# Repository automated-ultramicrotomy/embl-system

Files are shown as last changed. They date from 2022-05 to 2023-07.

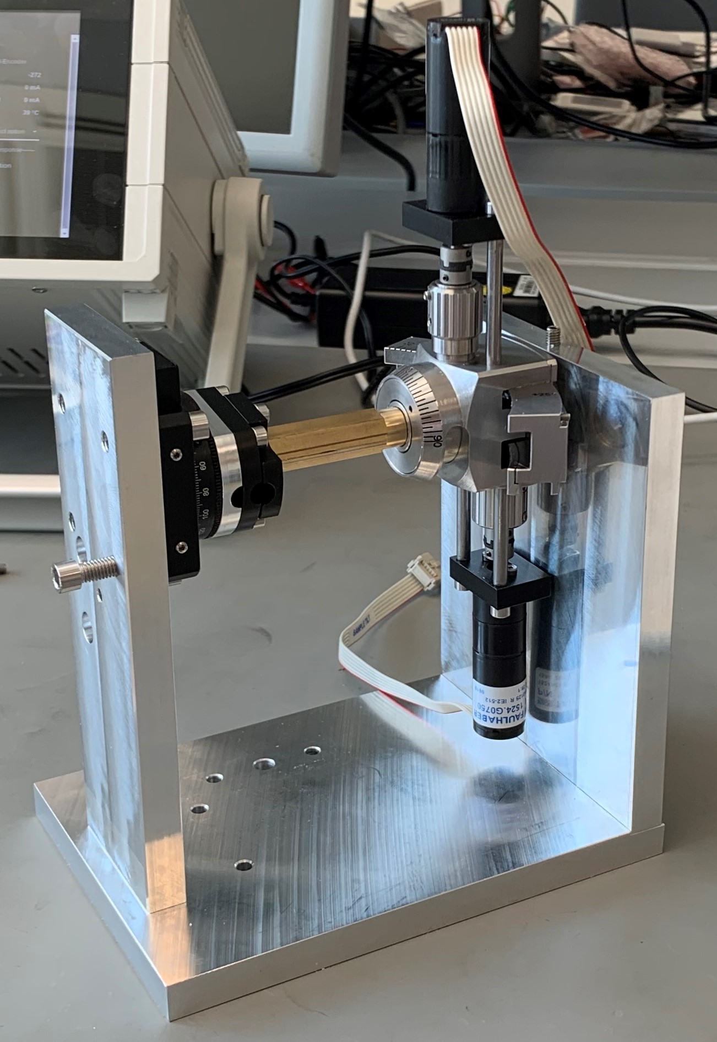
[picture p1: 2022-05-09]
Images/calibration/sample-rotation-images/sample-rotation-4.jpg

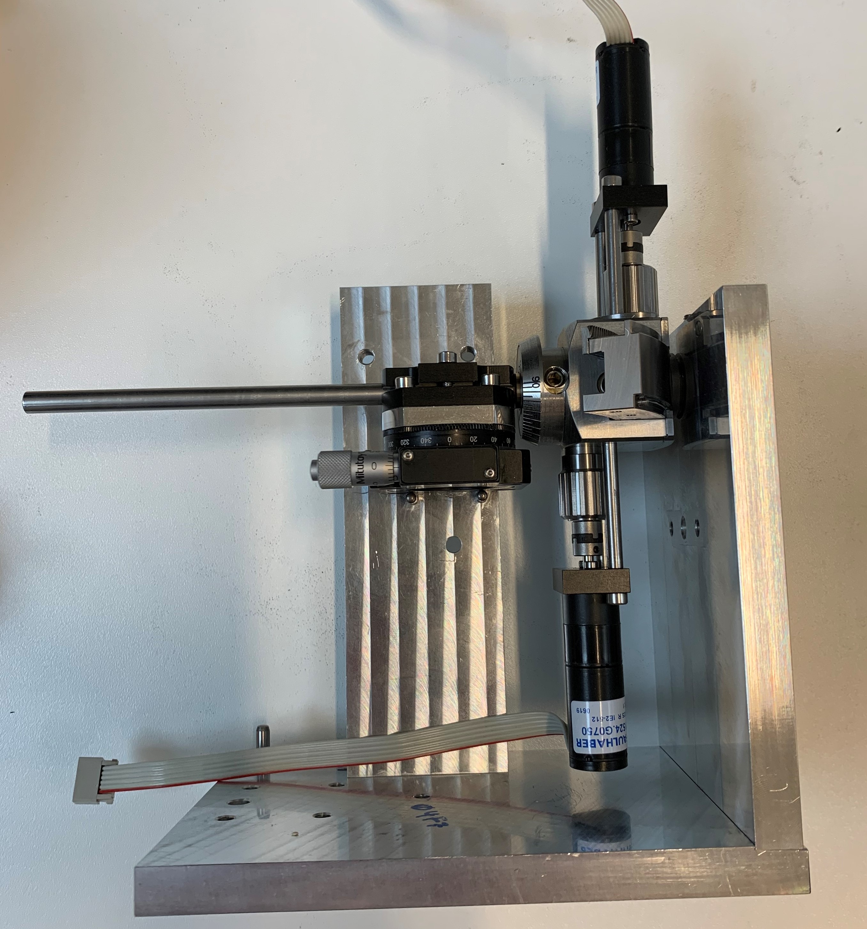
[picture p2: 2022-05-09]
Images/calibration/sample-tilt-images/sample-tilt-3.jpg

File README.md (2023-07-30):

# embl-system

Files for the motorised system from EMBL, built on a Leica UC7 ultramicrotome.

- **CAD Parts** - CAD models of the main parts
- **Code** - node-red flow for user interface
- **Images**  - diagrams / images of the system and subsystems
- **parts_list.pdf** - list of the main parts for the motorised system

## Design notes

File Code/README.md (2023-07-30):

# node-red

Files for the user-interface / electronics of the motorised system.

**node-red-flow.json** gives the entire 'flow' json for the user interface. Once Node-RED (https://nodered.org/) is installed,
the flow can be loaded by selecting `import` from the menu, and providing this `.json` file. 

This also requires the following nodes to be installed: 
  * node-red-dashboard (https://flows.nodered.org/node/node-red-dashboard), 
  * node-red-node-serialport (https://flows.nodered.org/node/node-red-node-serialport)

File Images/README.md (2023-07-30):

# System Images

Images/diagrams of different system components

- **box-images** - images of the interface box
- **calibration** - diagrams / images of the calibration setup
- **knife-tilt** - diagrams / images of the knife + motor
- **sample-tilt-rotation**  - diagrams / images of the arc + motors
- **user-interface** - screenshot images of the node-red flows for the user interface

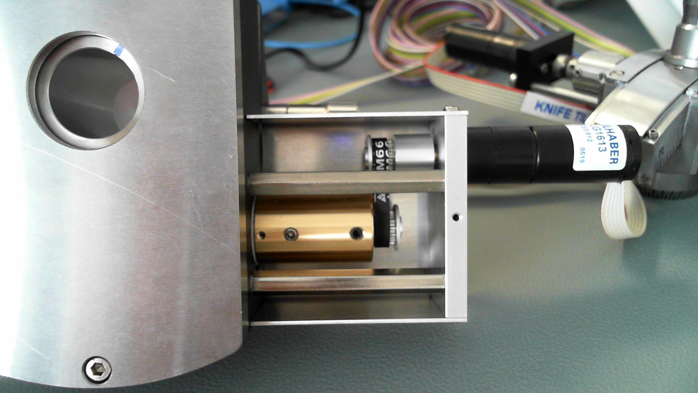
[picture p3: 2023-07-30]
Images/knife-tilt/knife_underside_3.jpg

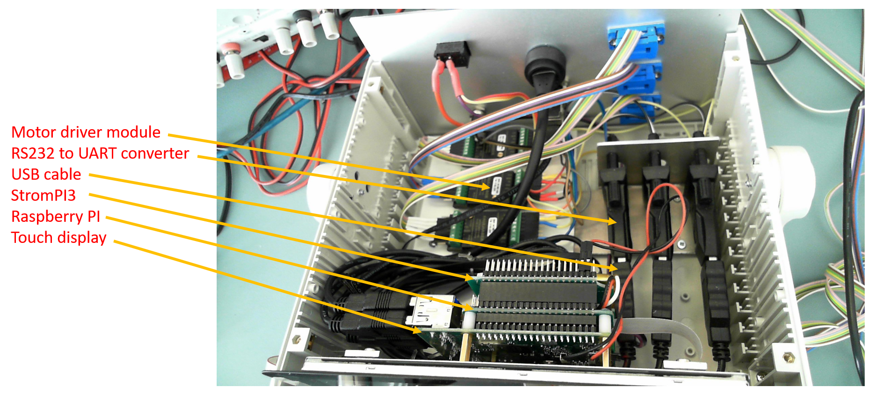
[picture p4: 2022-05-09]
Images/box-images/inside-the-box-with-labels.png

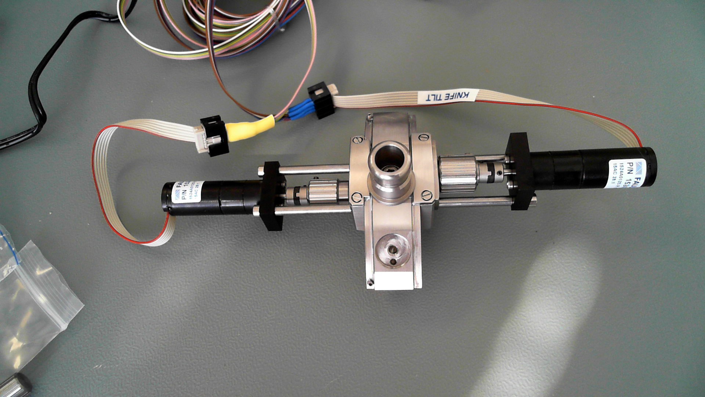
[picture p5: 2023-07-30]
Images/sample-tilt-rotation/arc_back_1.jpg

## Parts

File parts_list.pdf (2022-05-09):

Units | Item | Manufacturer | Reference
1 | Case Bopla UM 52011 L 224x198,9x72,4 | Distrelec | 150-43-162
1 | Netzgerät getaktet, 60W, 12Vdc / 5A (jack 2.1x5x5x11mm) | RS | 175-3285
2 | Motor Combi 1524A012S R IE2-512 15AC28:1 | FAULHABER | 1524.G0750
1 | Motor Combi 1524B012S R IE2-512 15AC52:1 | FAULHABER | 1524.G1613
3 | Controller MCDC3002 S RS | FAULHABER | 650,001,488
1 | Strom Pi 3 | Reichelt | RASP STROM PI 3
1 | Battery Raspberry Pi | Reichelt | RPI STROMPI AKKU
1 | Raspberry Pi 7" Touchscreen Display | Reichelt | RASPBERRY PI 7TD
1 | Raspberry Pi 3 B | Reichelt | Raspberry Pi 3 B
3 | USB 2.0 Kabel, A Stecker auf A Buchse, 30 cm | Reichelt | AK 669-0,3
3 | Delock USB2.0 auf Seriell Adapter RS232 | Reichelt | DELOCK 61460
1 | Panels | BetaLayout
4 | Synchronscheiben (rotaciones) | Misumi | HTPA15S2M040-K-P3
2 | Super Torque S2M 4mm x 66mm (belts) | Misumi | 40S2M66
2 | Flex joint | Misumi | MCO8-3-3
1 | USB connector panel | Digi-Key | APC1748-ND
1 | Ethernet connector panel | Digi-Key | EHRJ45P6S-ND
1 | TC-R13-66A-02 switch 250V/6A | Conrad El. | 1587515 - 62
1 | CONN PWR JACK 2X5.5MM | Digi-Key | CP-065A-ND
3 | WR-DSUB Female IDC Connector | Würth | 618 009 227 221
3 | WR-DSUB Male IDC Connector | Würth | 618 009 221 823
3 | WR-DSUB Plastic Hood, 9 pins | Würth | 618 009 253 22

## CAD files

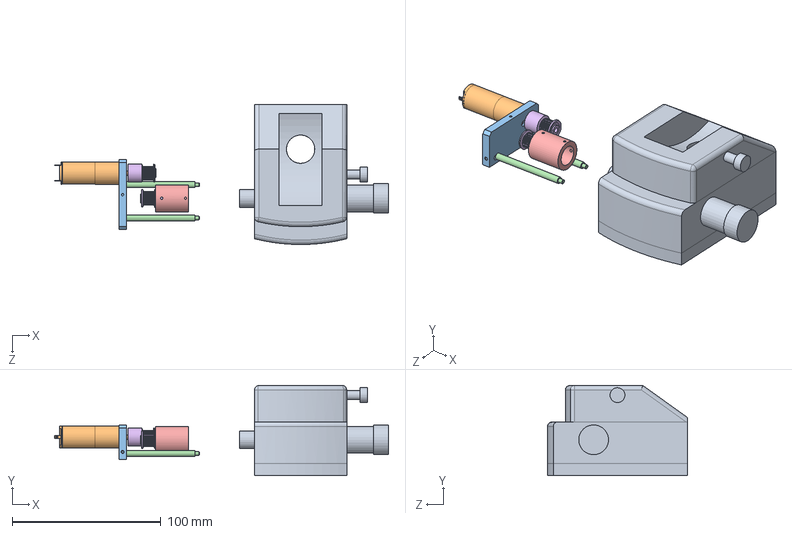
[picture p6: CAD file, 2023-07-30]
CAD Parts/Solidworks 2022 Models/knife-tilt/BG-YS-Messturm-01.SLDASM
224.2 x 60.5 x 94.0 mm
Messturm
1524T_SR
50-AL-0002-00
50-AL-0005-00 x 2
50-AL-0004-00
_HTPA15S2M060-K-H3_a.stp x 2

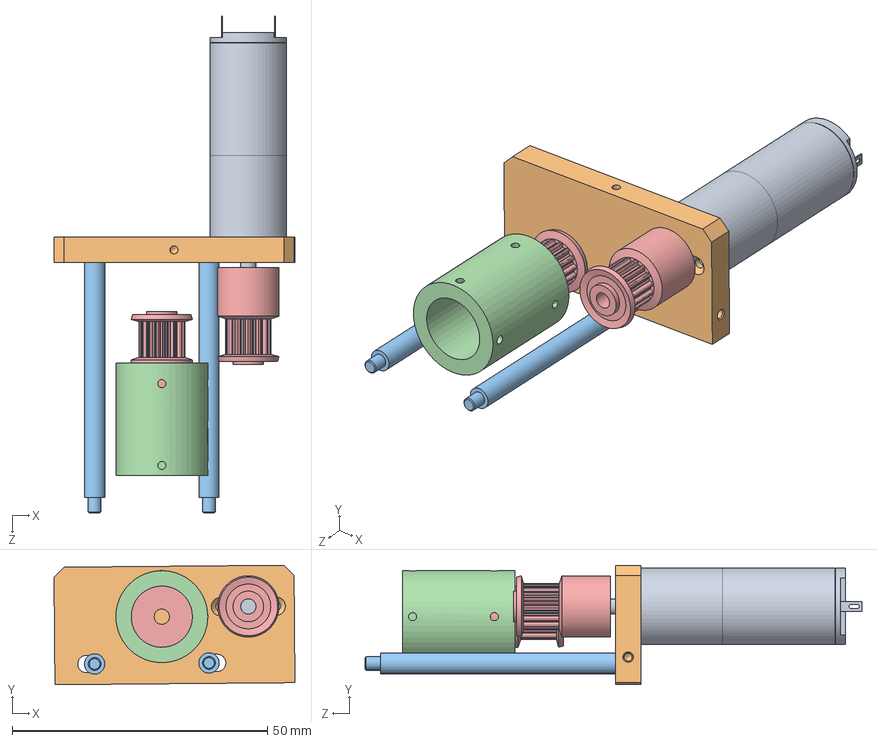
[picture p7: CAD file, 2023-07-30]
CAD Parts/Solidworks 2022 Models/knife-tilt/motor-mount/BG-Alfons-0000-00.SLDASM
47.2 x 23.4 x 97.2 mm
1524T_SR
50-AL-0002-00
50-AL-0005-00 x 2
50-AL-0004-00
_HTPA15S2M060-K-H3_a.stp x 2

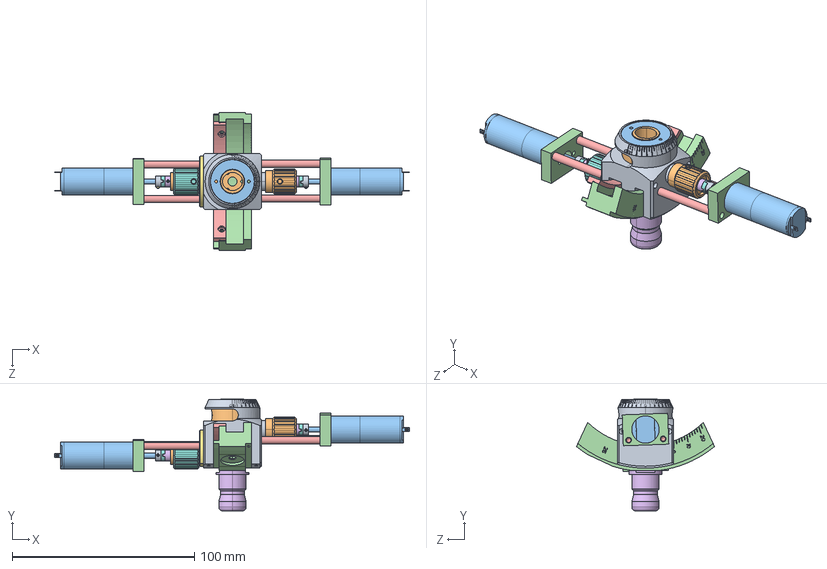
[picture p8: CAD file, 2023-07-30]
CAD Parts/Solidworks 2022 Models/sample-tilt-rotation/BG-YS-Segmentbogen-01.SLDASM
195.0 x 61.4 x 75.9 mm
16-708-031-109-Z-0000.stp
701731745.stp
16-705-831-540-Z-0000.stp
702531341.stp
702531342.stp
705831360.stp
702531344.stp
705831361.stp
700331086.stp
705831362.stp
1524T_SR x 2
50-AL-0001-00 x 2
50-AL-0005-00 x 4
_MCO6-1.5-1.5_co.stp x 2
_SET-SCREW1.6-3.stp x 4
_MCO_spacer6_s.stp x 2
_MCO6-1.5-1.5_co_r.stp x 2
50-AL-0006-00 x 2

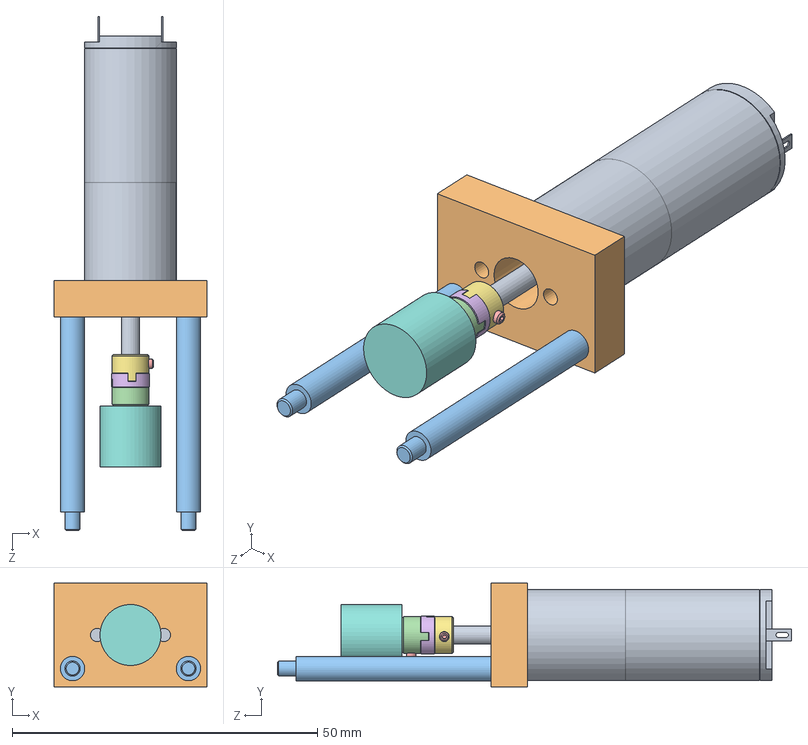
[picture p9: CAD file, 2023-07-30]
CAD Parts/Solidworks 2022 Models/sample-tilt-rotation/motor-mount/BG-Alfons-0001-00.SLDASM
25.0 x 17.0 x 84.2 mm
1524T_SR
50-AL-0001-00
50-AL-0005-00 x 2
_MCO6-1.5-1.5_co.stp
_SET-SCREW1.6-3.stp x 2
_MCO_spacer6_s.stp
_MCO6-1.5-1.5_co_r.stp
50-AL-0006-00

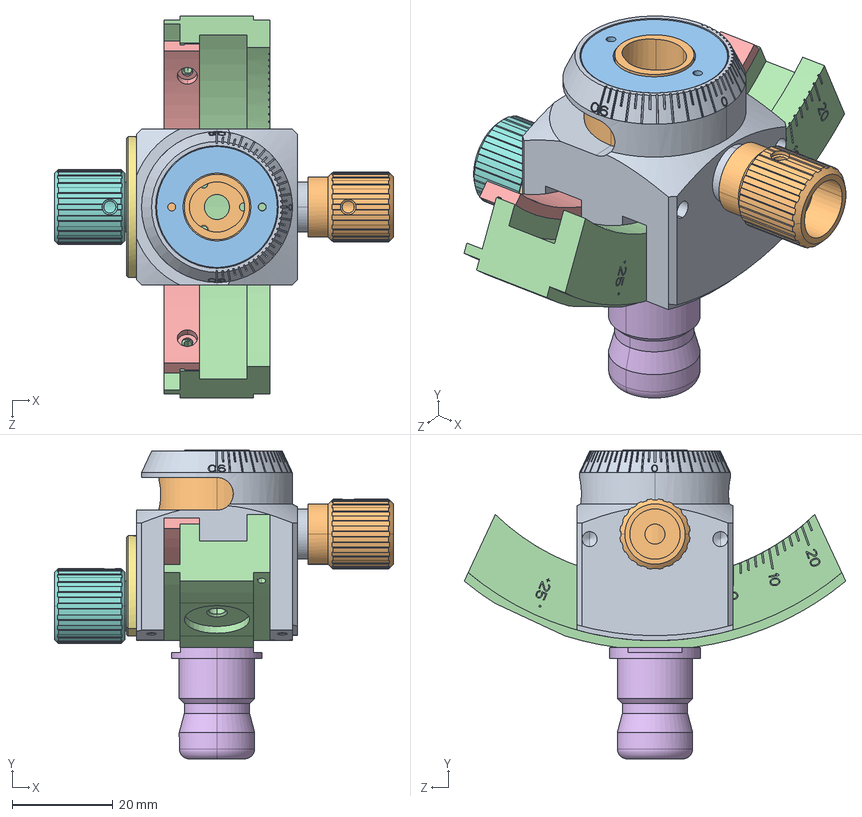
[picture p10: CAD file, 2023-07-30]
CAD Parts/Solidworks 2022 Models/sample-tilt-rotation/sample-arc/Segmentbogen.SLDASM
67.4 x 61.4 x 75.9 mm
16-708-031-109-Z-0000.stp
701731745.stp
16-705-831-540-Z-0000.stp
702531341.stp
702531342.stp
705831360.stp
702531344.stp
705831361.stp
700331086.stp
705831362.stp

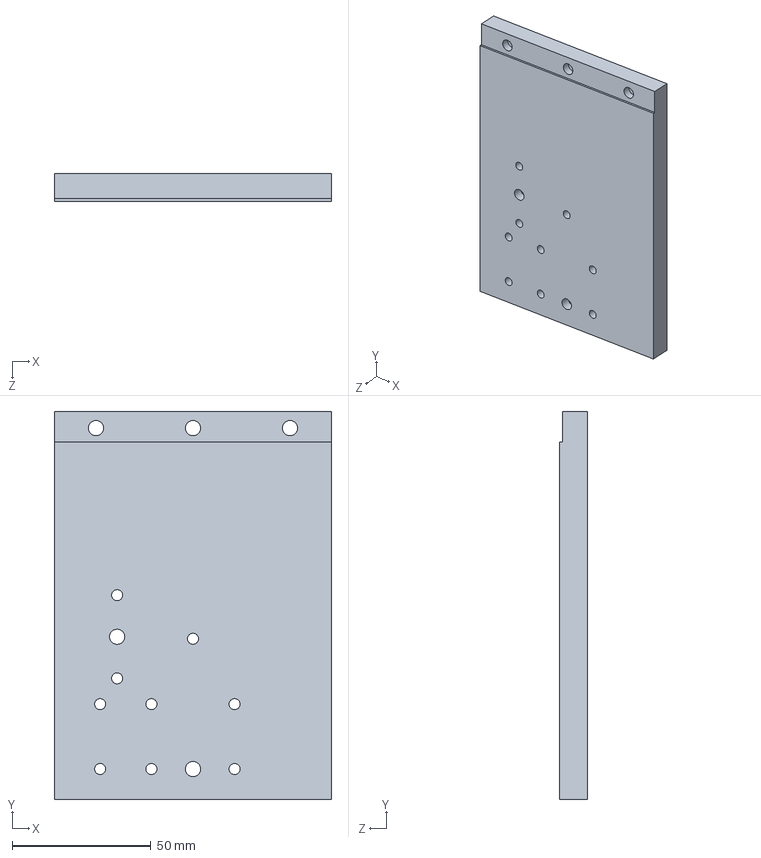
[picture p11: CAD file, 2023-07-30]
CAD Parts/Solidworks 2022 Models/Calibration/30-YS/30-YS-0008-00.SLDPRT
100.0 x 140.0 x 10.0 mm

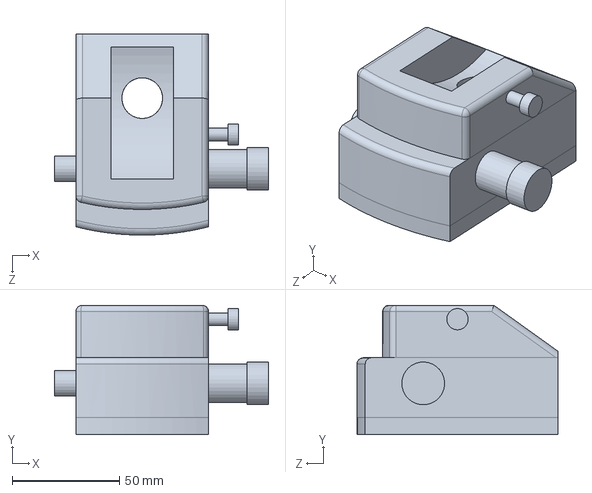
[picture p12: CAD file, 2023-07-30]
CAD Parts/Solidworks 2022 Models/knife-tilt/knife-block/Messturm.SLDPRT
100.0 x 60.5 x 94.0 mm

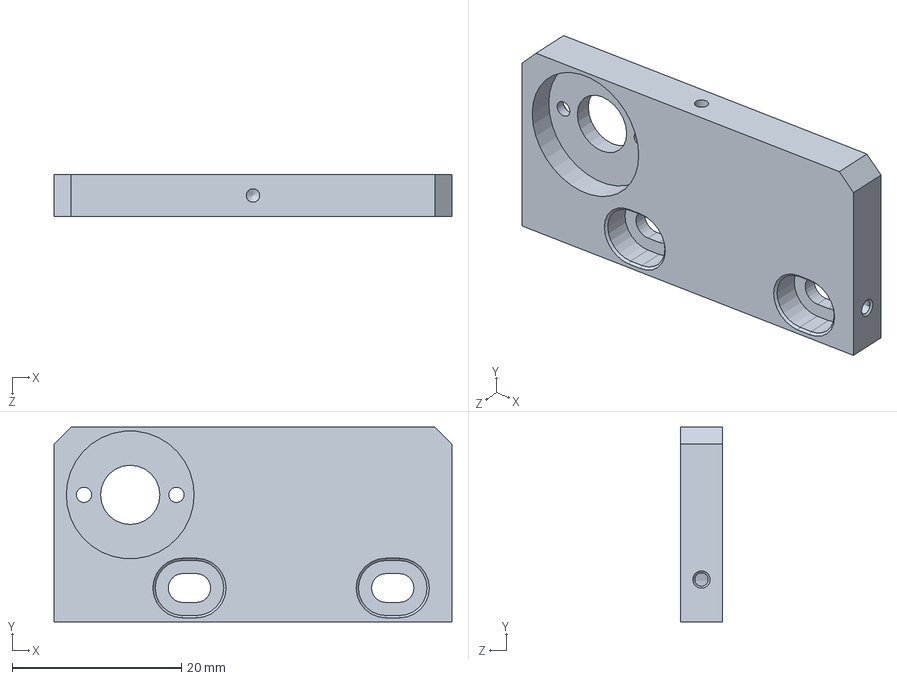
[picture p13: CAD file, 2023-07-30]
CAD Parts/Solidworks 2022 Models/knife-tilt/motor-mount/50-AL/50-AL-0002-00.SLDPRT
47.0 x 23.0 x 5.00 mm

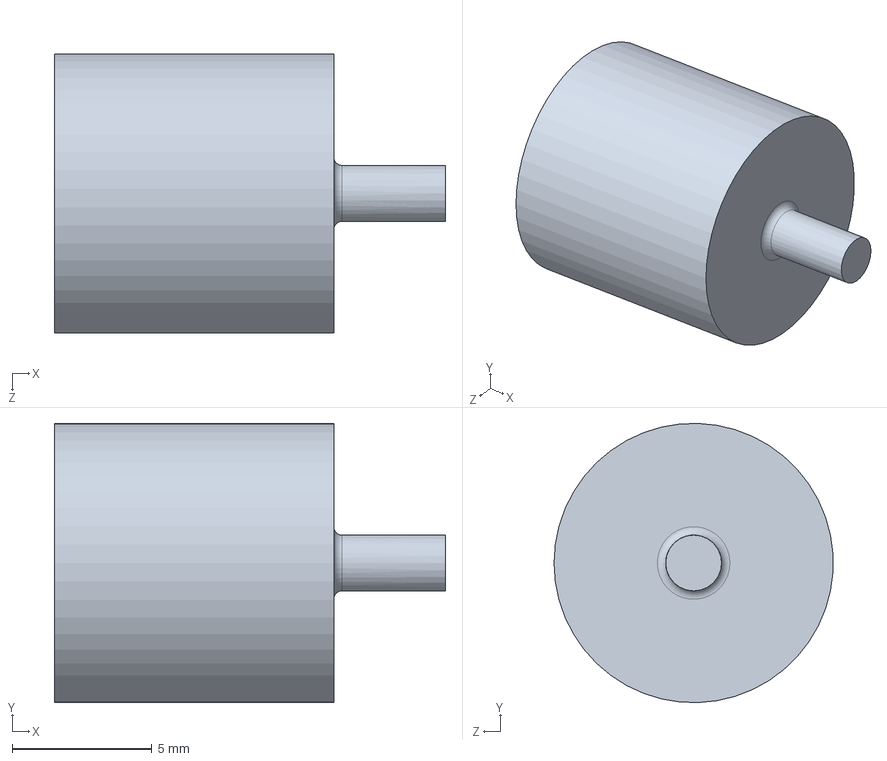
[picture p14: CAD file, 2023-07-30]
CAD Parts/Solidworks 2022 Models/sample-tilt-rotation/motor-mount/50-AL/50-AL-0006-00.SLDPRT
14.0 x 9.99 x 9.99 mm

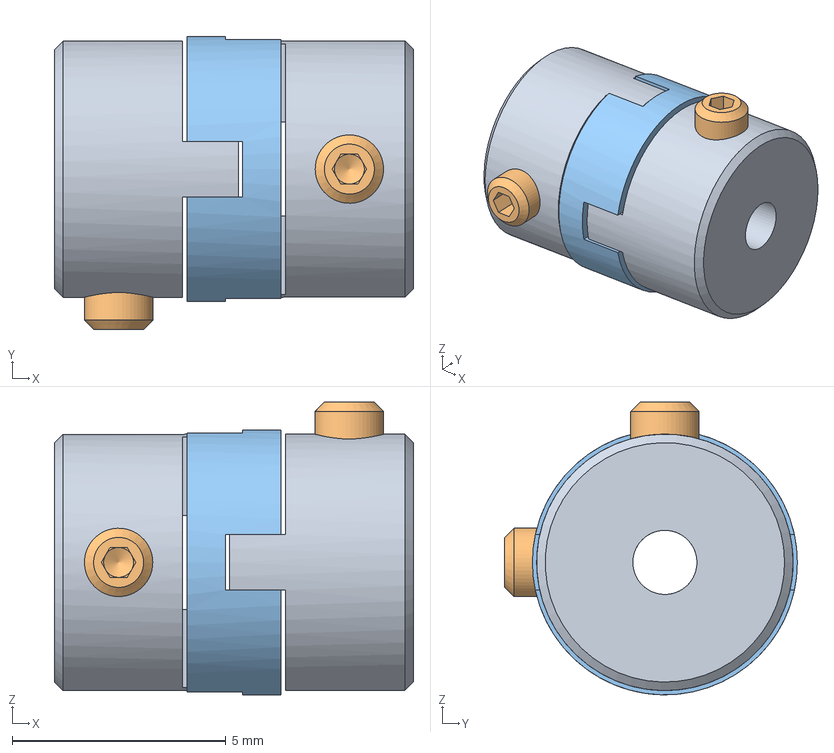
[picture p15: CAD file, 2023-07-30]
CAD Parts/Solidworks 2022 Models/sample-tilt-rotation/motor-mount/OTS/MCO6-1.5-1.5.stp
8.40 x 6.85 x 6.85 mm
_MCO6-1.5-1.5_co
_SET-SCREW1.6-3 x 2
_MCO_spacer6_s
_MCO6-1.5-1.5_co_r

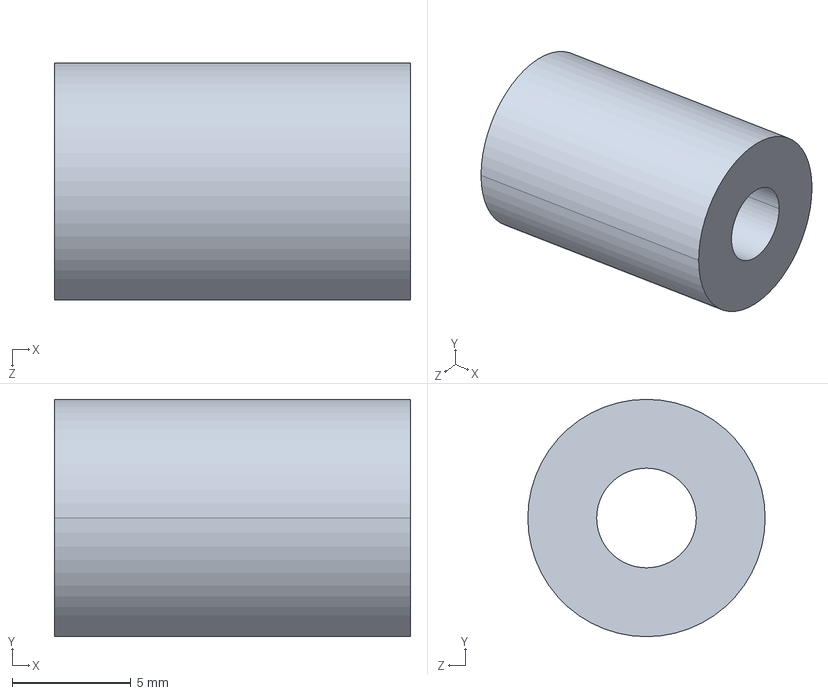
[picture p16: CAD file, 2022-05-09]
CAD Parts/STEP Models/calibration/30-YS-0005-01.STEP
15.0 x 10.00 x 10.00 mm

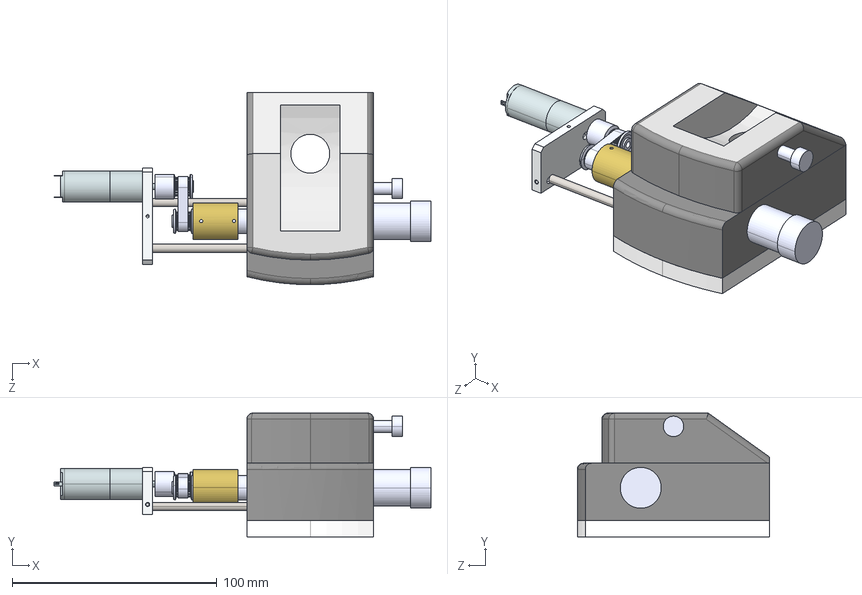
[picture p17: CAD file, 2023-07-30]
CAD Parts/STEP Models/knife-tilt/BG-YS-Messturm-01.STEP
184.2 x 60.5 x 94.0 mm
Messturm_Standard
1524T_SR_Standard
50-AL-0002-00_Standard
50-AL-0005-00_L=58 x 2
50-AL-0004-00_Standard
_HTPA15S2M060-K-H3_a.stp_Standard x 2
Misumi_40S2M66_Standard

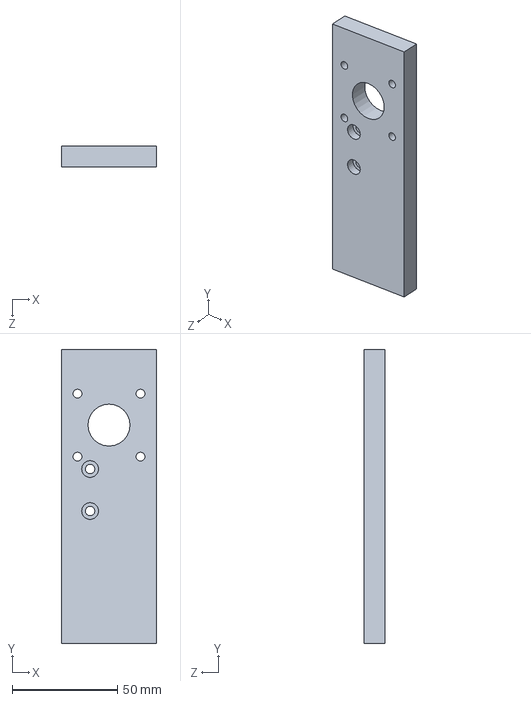
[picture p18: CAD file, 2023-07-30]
CAD Parts/Solidworks 2022 Models/Calibration/30-YS/30-YS-0009-00.SLDPRT
45.0 x 140.0 x 10.0 mm

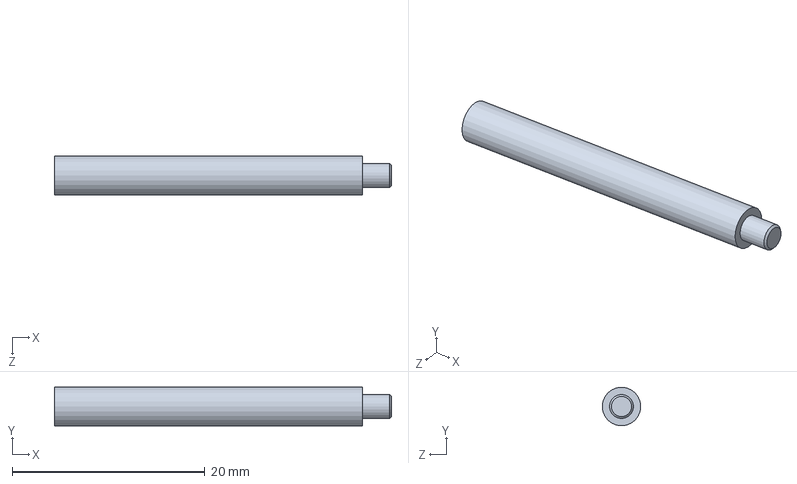
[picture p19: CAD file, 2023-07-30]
CAD Parts/Solidworks 2022 Models/knife-tilt/motor-mount/50-AL/50-AL-0005-00.SLDPRT
35.0 x 4.00 x 4.00 mm

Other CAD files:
CAD Parts/STEP Models/sample-tilt-rotation/Segmentbogen.stp
CAD Parts/Solidworks 2022 Models/knife-tilt/motor-mount/OTS/HTPA15S2M060-K-H3.stp
CAD Parts/Solidworks 2022 Models/sample-tilt-rotation/motor-mount/50-AL/50-AL-0001-00.SLDPRT
CAD Parts/Solidworks 2022 Models/sample-tilt-rotation/motor-mount/OTS/1524T_SR.SLDPRT
CAD Parts/STEP Models/calibration/30-YS-0002-00.STEP
CAD Parts/STEP Models/calibration/30-YS-0003-00.STEP
CAD Parts/STEP Models/calibration/30-YS-0004-00.STEP
CAD Parts/STEP Models/calibration/30-YS-0006-00.STEP
CAD Parts/STEP Models/calibration/30-YS-0007-00.STEP
CAD Parts/STEP Models/calibration/30-YS-0008-00.STEP
CAD Parts/STEP Models/calibration/30-YS-0009-00.STEP
CAD Parts/Solidworks 2022 Models/Calibration/30-YS/30-YS-0002-00.SLDDRW
CAD Parts/Solidworks 2022 Models/Calibration/30-YS/30-YS-0002-00.SLDPRT
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

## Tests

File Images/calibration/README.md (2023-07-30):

# calibration

Files for the calibration setup for the EMBL motorised system, built on a Leica UC7 ultramicrotome.

Overview diagram in **BG-YS-Segmentbogen.pdf** - note that these pieces are assembled in different configurations to 
calibrate the knife tilt, sample rotation and sample tilt (see images in the corresponding folders). This diagram shows the 
setup for the sample tilt calibration. CAD files are provided for the labelled pieces in this diagram in the 'CAD Parts' folder.
Note the additional '30-YS-0006-00.STEP' file - this piece is only used in the knife tilt and sample rotation calibration, and so
isn't shown in this diagram.

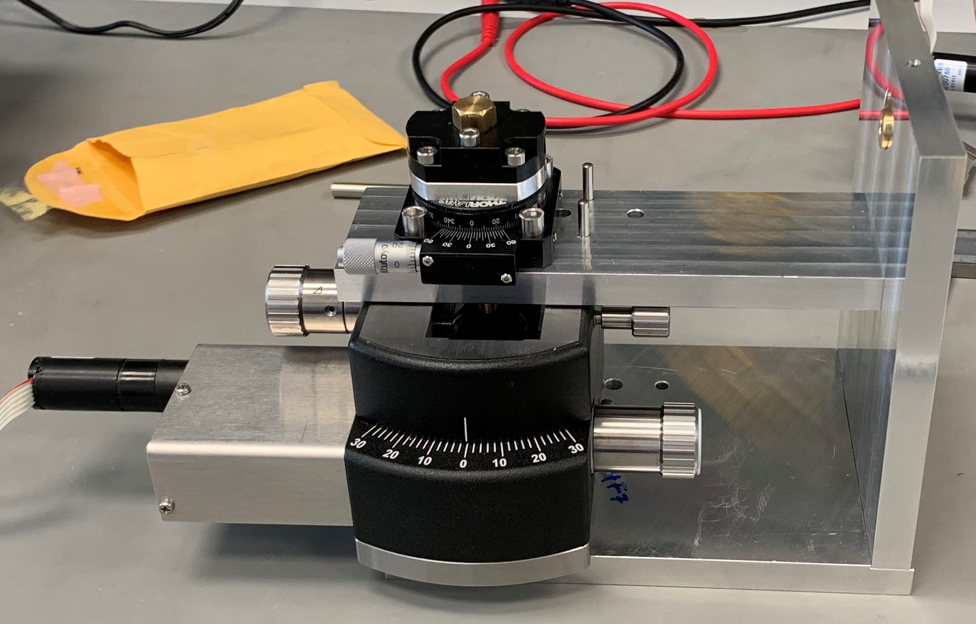
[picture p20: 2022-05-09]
Images/calibration/knife-tilt-images/knife-calibration-1.jpg

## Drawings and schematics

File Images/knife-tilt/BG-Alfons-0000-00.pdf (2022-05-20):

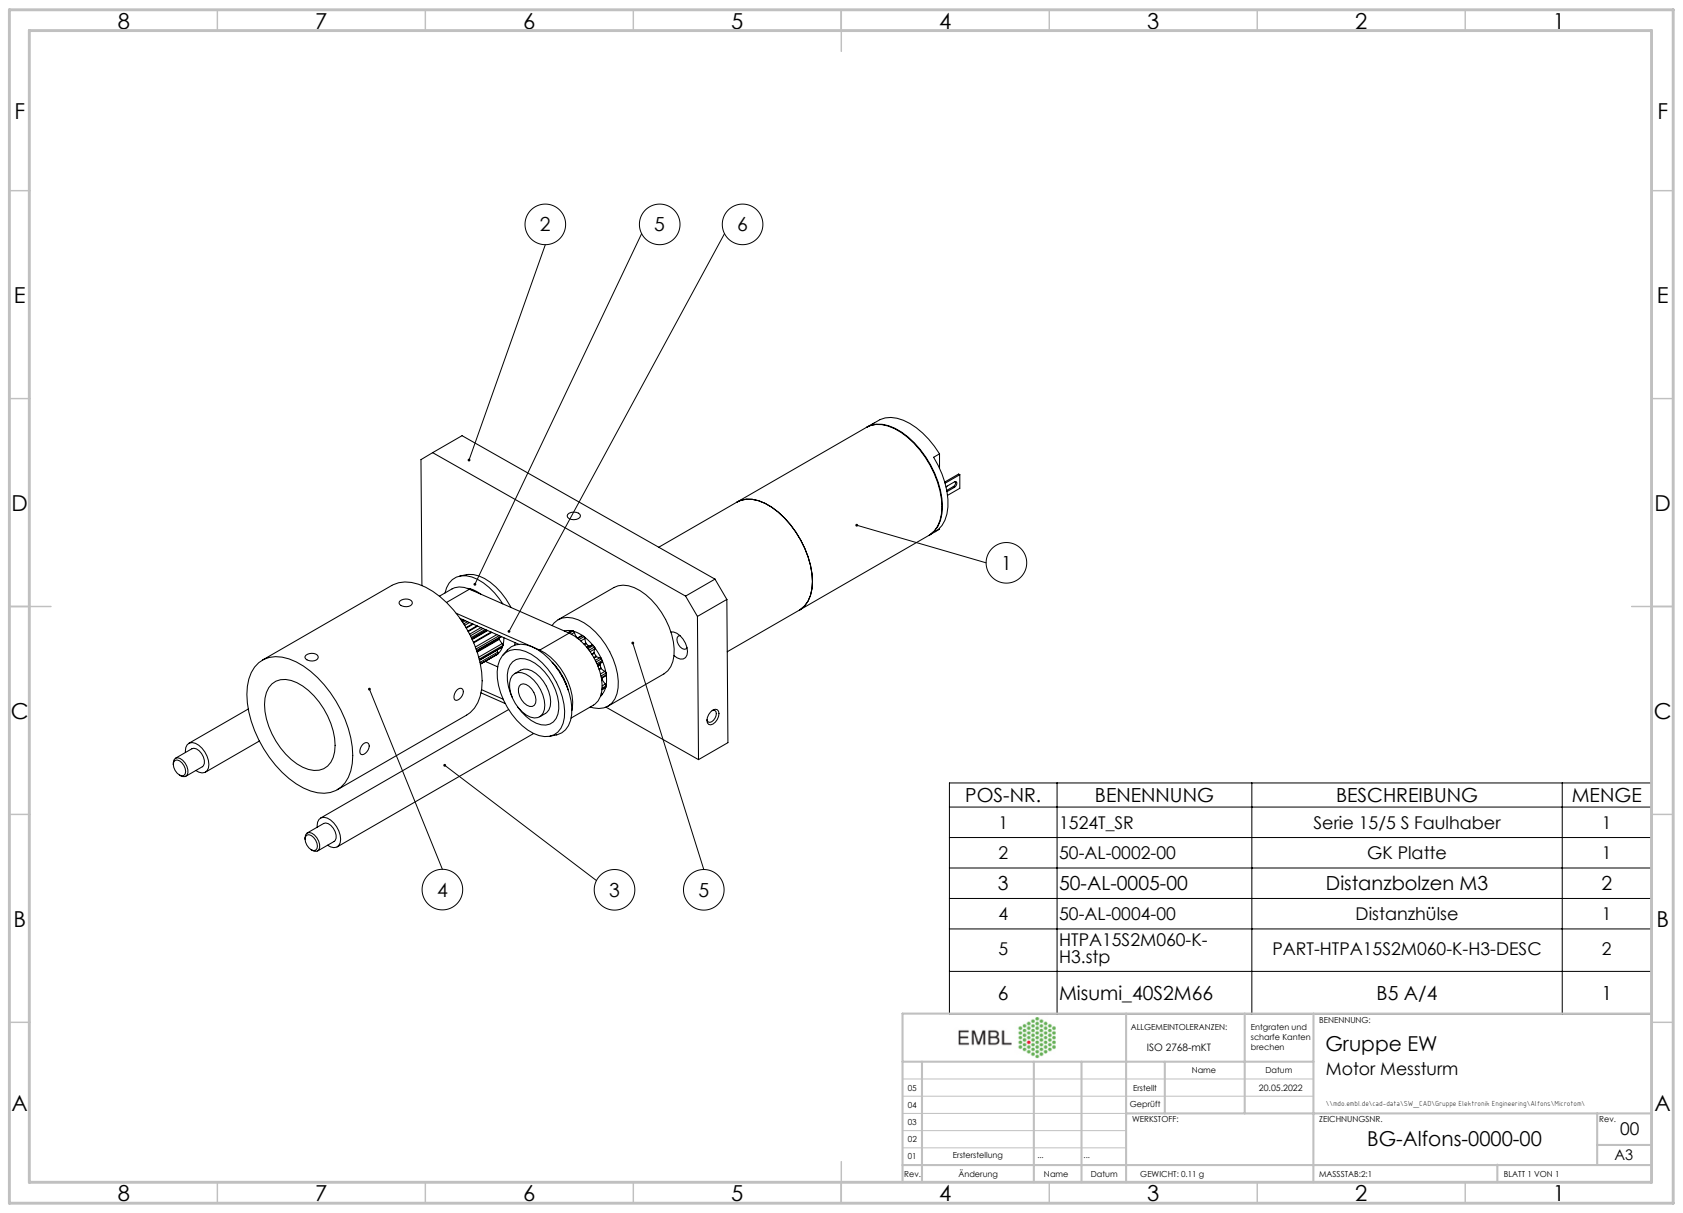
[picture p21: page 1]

POS-NR. | BENENNUNG | BESCHREIBUNG | MENGE
1 | 1524T_SR | Serie 15/5 S Faulhaber | 1
2 | 50-AL-0002-00 | GK Platte | 1
3 | 50-AL-0005-00 | Distanzbolzen M3 | 2
4 | 50-AL-0004-00 | Distanzhülse | 1
5 | HTPA15S2M060-K-H3.stp | PART-HTPA15S2M060-K-H3-DESC | 2

6 | Misumi_40S2M66 | B5 A/4 | 1

ALLGEMEINTOLERANZEN: ISO 2768-mKT | Entgraten und scharfe Kanten brechen | BENENNUNG: Gruppe EW Motor Messturm \\mdo.embl.de\cad-data\SW_CAD\Gruppe Elektronik Engineering\Alfons\Microtom\

Name | Datum

05 | | | | Erstellt | | 20.05.2022
04 | | | | Geprüft
03 | | | | WERKSTOFF: | ZEICHNUNGSNR. BG-Alfons-0000-00 | Rev. 00
02
01 | Ersterstellung | ... | ... | | | A3

Rev. | Änderung | Name | Datum | GEWICHT: 0.11 g | MASSSTAB:2:1 | BLATT 1 VON 1

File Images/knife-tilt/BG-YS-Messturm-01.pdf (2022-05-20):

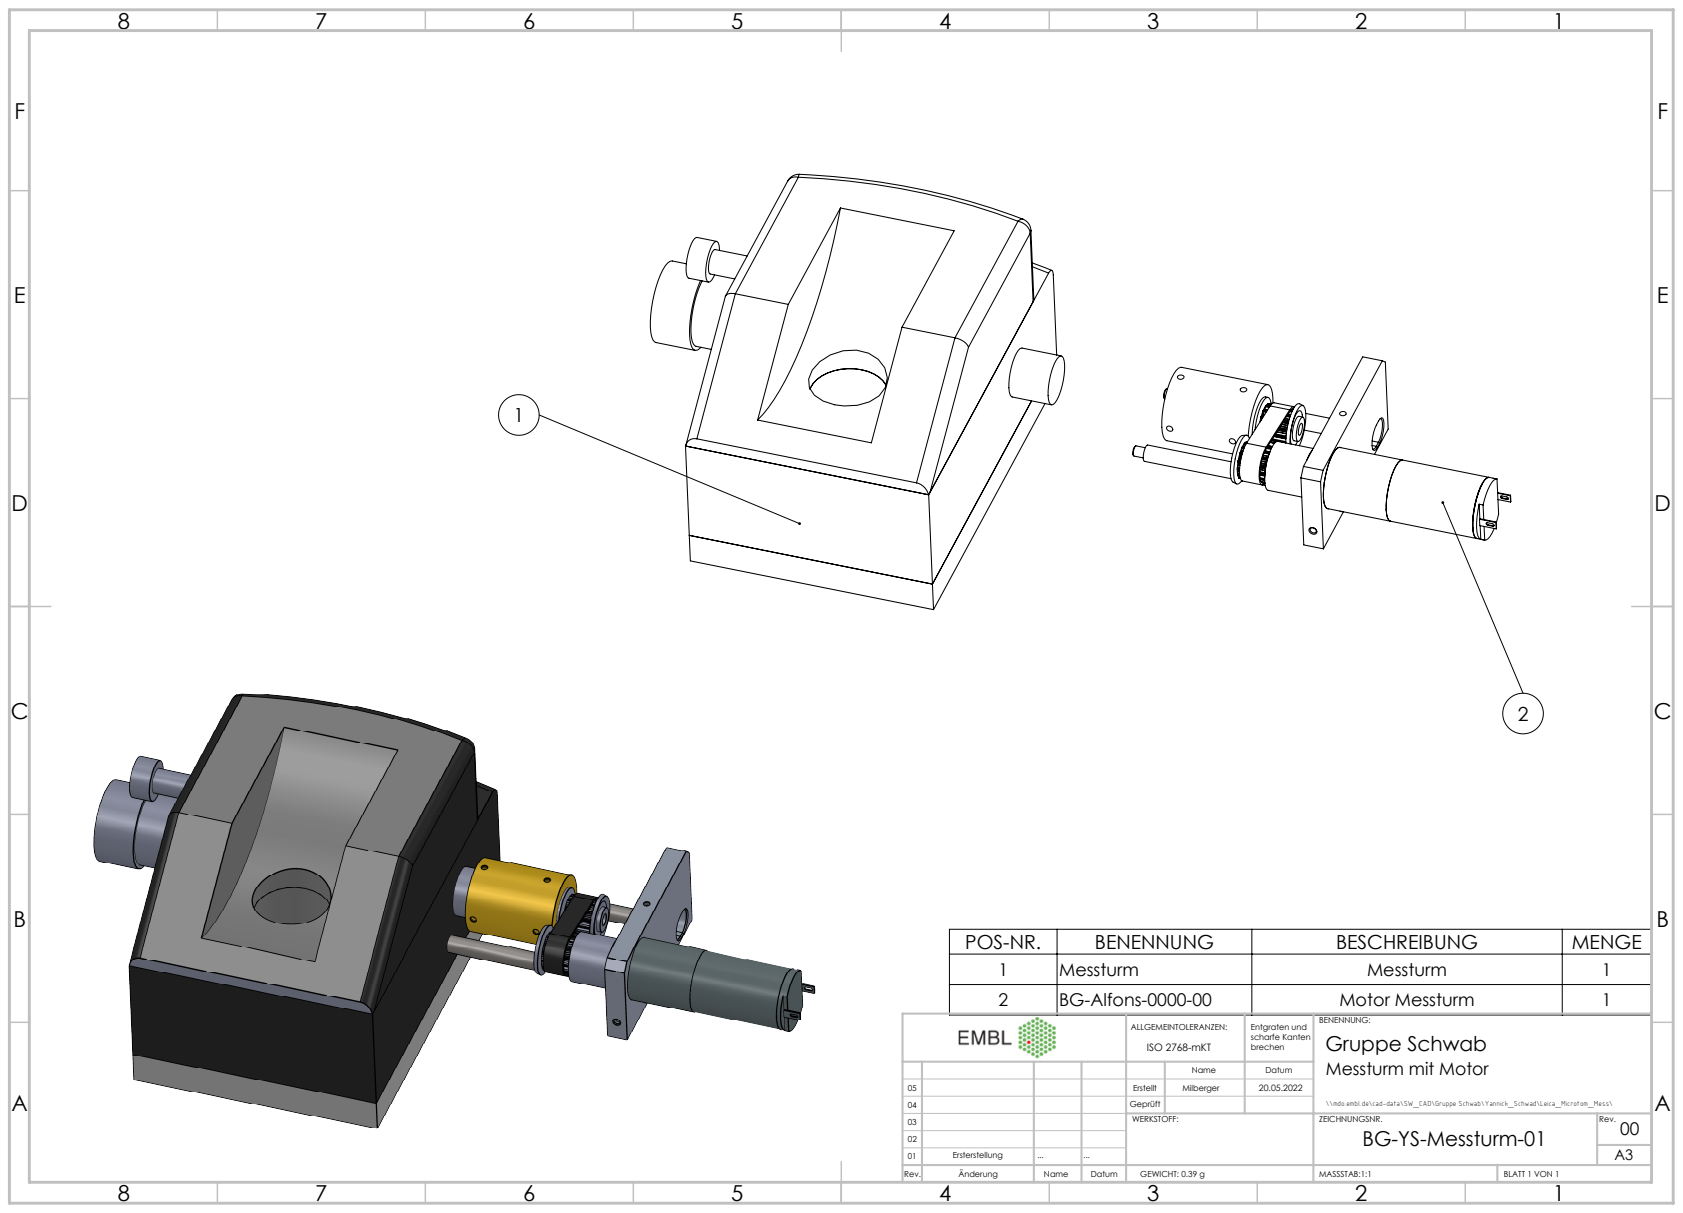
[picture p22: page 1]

POS-NR. | BENENNUNG | BESCHREIBUNG | MENGE
1 | Messturm | Messturm | 1
2 | BG-Alfons-0000-00 | Motor Messturm | 1

ALLGEMEINTOLERANZEN: ISO 2768-mKT | Entgraten und scharfe Kanten brechen | BENENNUNG: Gruppe Schwab Messturm mit Motor \\mdo.embl.de\cad-data\SW_CAD\Gruppe Schwab\Yannick_Schwad\Leica_Microtom_Mess\

Name | Datum

05 | | | | Erstellt | Milberger | 20.05.2022
04 | | | | Geprüft
03 | | | | WERKSTOFF: | ZEICHNUNGSNR. BG-YS-Messturm-01 | Rev. 00
02
01 | Ersterstellung | ... | ... | | | A3

Rev. | Änderung | Name | Datum | GEWICHT: 0.39 g | MASSSTAB:1:1 | BLATT 1 VON 1

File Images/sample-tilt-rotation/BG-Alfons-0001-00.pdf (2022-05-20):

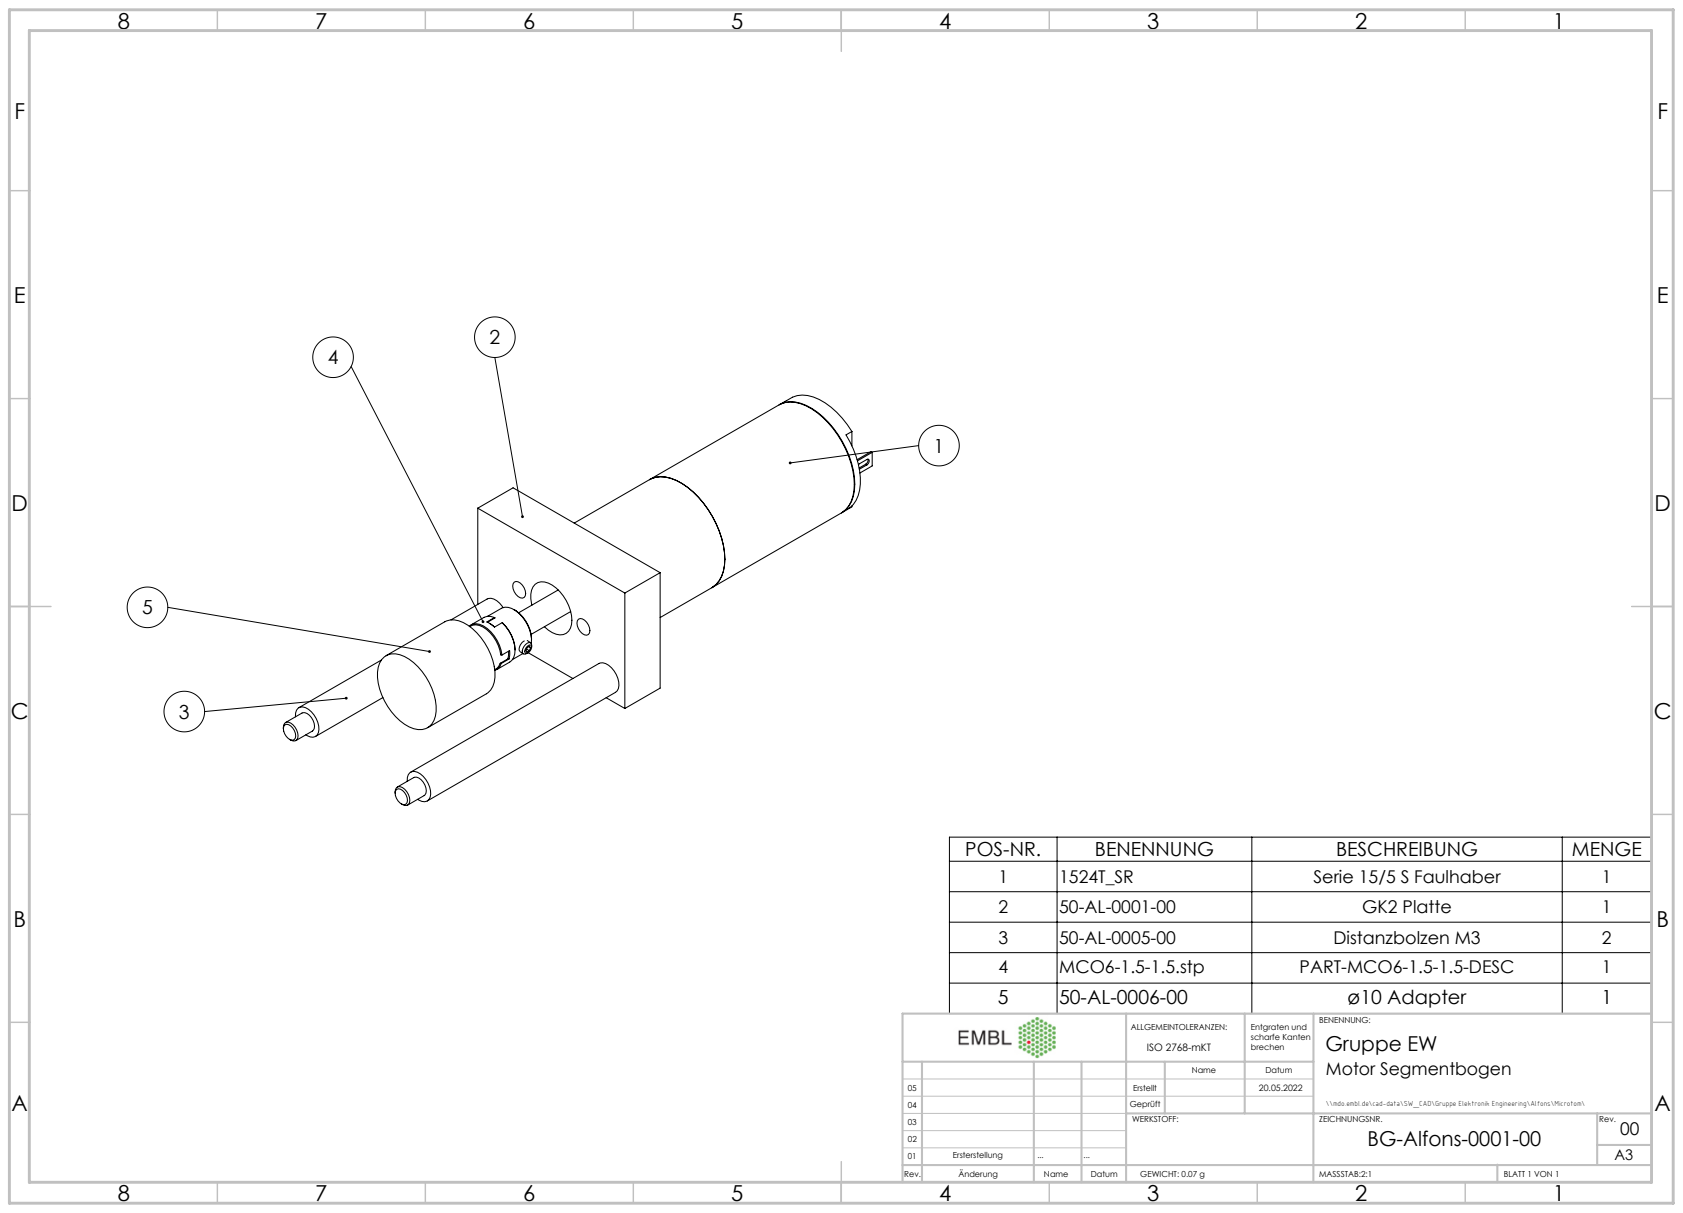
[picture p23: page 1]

POS-NR. | BENENNUNG | BESCHREIBUNG | MENGE
1 | 1524T_SR | Serie 15/5 S Faulhaber | 1
2 | 50-AL-0001-00 | GK2 Platte | 1
3 | 50-AL-0005-00 | Distanzbolzen M3 | 2
4 | MCO6-1.5-1.5.stp | PART-MCO6-1.5-1.5-DESC | 1
5 | 50-AL-0006-00 | ø10 Adapter | 1

ALLGEMEINTOLERANZEN: ISO 2768-mKT | Entgraten und scharfe Kanten brechen | BENENNUNG: Gruppe EW Motor Segmentbogen \\mdo.embl.de\cad-data\SW_CAD\Gruppe Elektronik Engineering\Alfons\Microtom\

Name | Datum

05 | | | | Erstellt | | 20.05.2022
04 | | | | Geprüft
03 | | | | WERKSTOFF: | ZEICHNUNGSNR. BG-Alfons-0001-00 | Rev. 00
02
01 | Ersterstellung | ... | ... | | | A3

Rev. | Änderung | Name | Datum | GEWICHT: 0.07 g | MASSSTAB:2:1 | BLATT 1 VON 1

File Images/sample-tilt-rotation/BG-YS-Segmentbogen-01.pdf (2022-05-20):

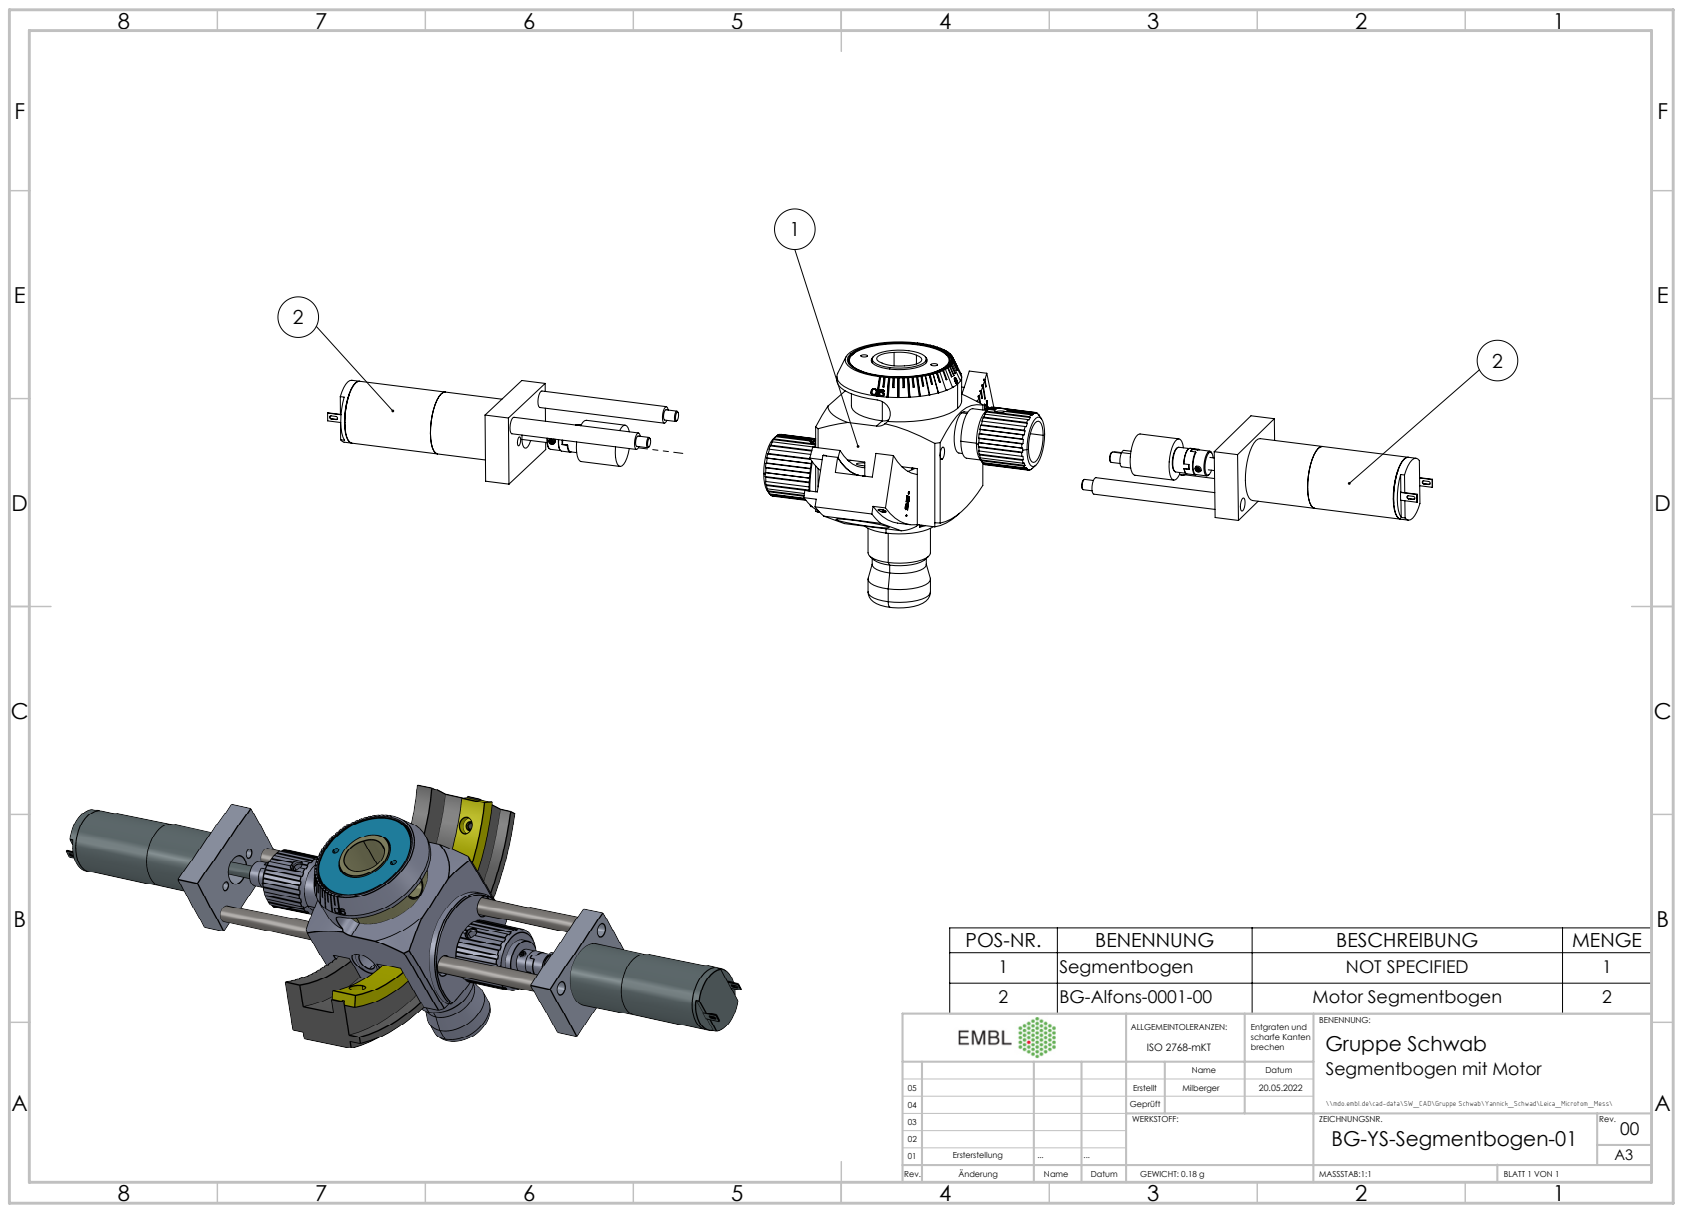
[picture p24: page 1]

POS-NR. | BENENNUNG | BESCHREIBUNG | MENGE
1 | Segmentbogen | NOT SPECIFIED | 1
2 | BG-Alfons-0001-00 | Motor Segmentbogen | 2

ALLGEMEINTOLERANZEN: ISO 2768-mKT | Entgraten und scharfe Kanten brechen | BENENNUNG: Gruppe Schwab Segmentbogen mit Motor \\mdo.embl.de\cad-data\SW_CAD\Gruppe Schwab\Yannick_Schwad\Leica_Microtom_Mess\

Name | Datum

05 | | | | Erstellt | Milberger | 20.05.2022
04 | | | | Geprüft
03 | | | | WERKSTOFF: | ZEICHNUNGSNR. BG-YS-Segmentbogen-01 | Rev. 00
02
01 | Ersterstellung | ... | ... | | | A3

Rev. | Änderung | Name | Datum | GEWICHT: 0.18 g | MASSSTAB:1:1 | BLATT 1 VON 1

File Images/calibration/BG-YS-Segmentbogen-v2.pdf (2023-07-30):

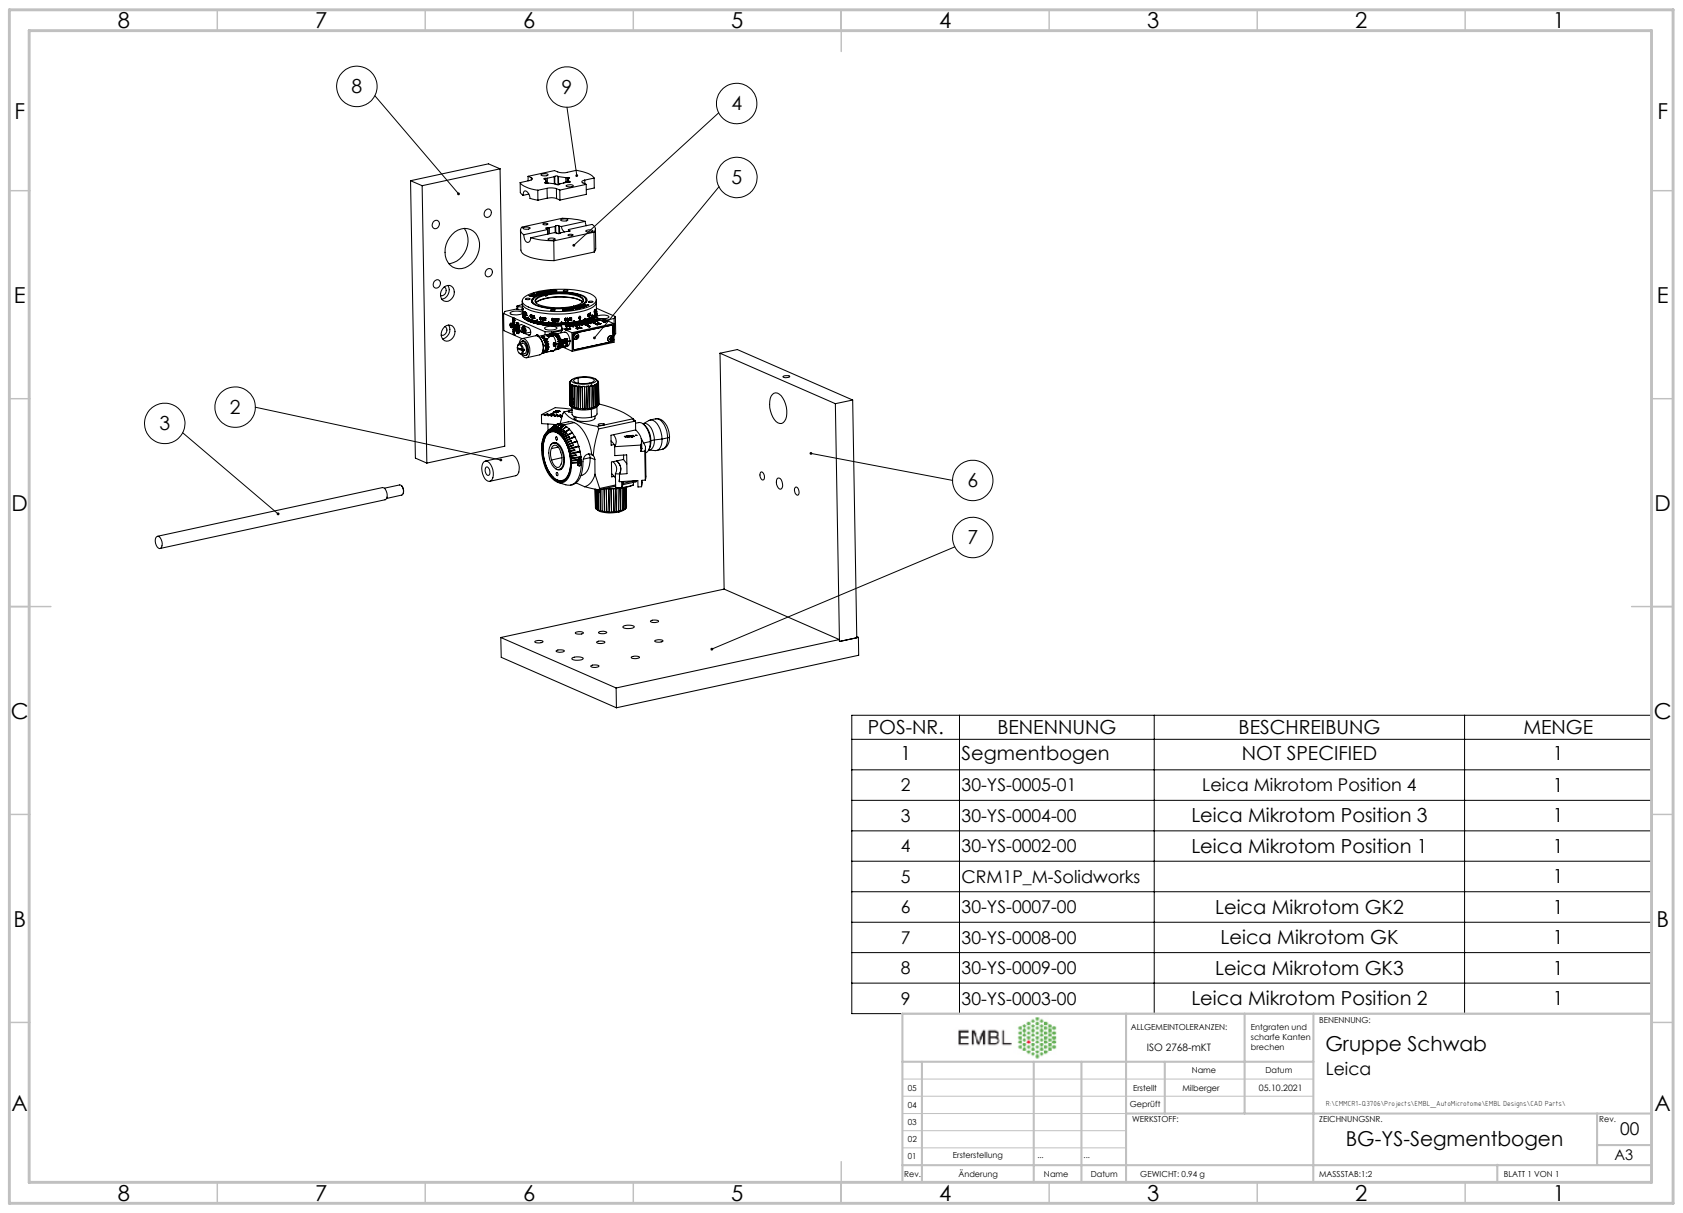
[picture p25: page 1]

POS-NR. | BENENNUNG | BESCHREIBUNG | MENGE
1 | Segmentbogen | NOT SPECIFIED | 1
2 | 30-YS-0005-01 | Leica Mikrotom Position 4 | 1
3 | 30-YS-0004-00 | Leica Mikrotom Position 3 | 1
4 | 30-YS-0002-00 | Leica Mikrotom Position 1 | 1
5 | CRM1P_M-Solidworks | | 1
6 | 30-YS-0007-00 | Leica Mikrotom GK2 | 1
7 | 30-YS-0008-00 | Leica Mikrotom GK | 1
8 | 30-YS-0009-00 | Leica Mikrotom GK3 | 1
9 | 30-YS-0003-00 | Leica Mikrotom Position 2 | 1

ALLGEMEINTOLERANZEN: ISO 2768-mKT | Entgraten und scharfe Kanten brechen | BENENNUNG: Gruppe Schwab Leica R:\CMMCR1-Q3706\Projects\EMBL_AutoMicrotome\EMBL Designs\CAD Parts\

Name | Datum

05 | | | | Erstellt | Milberger | 05.10.2021
04 | | | | Geprüft
03 | | | | WERKSTOFF: | ZEICHNUNGSNR. BG-YS-Segmentbogen | Rev. 00
02
01 | Ersterstellung | ... | ... | | | A3

Rev. | Änderung | Name | Datum | GEWICHT: 0.94 g | MASSSTAB:1:2 | BLATT 1 VON 1

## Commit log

2022-05-09 add leica files
    [30-YS-0002-00.STEP, 30-YS-0003-00.STEP, 30-YS-0004-00.STEP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]
2023-06-09 Restructured files and inserted missing CAD files.
    [1524T_SR.SLDPRT, 16-705-831-540-Z-0000.stp.SLDPRT, 16-708-031-109-Z-0000.stp.SLDPRT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]
2023-06-09 Some missing files and removing old directory structure
    [30-YS-0002-00.STEP, 30-YS-0003-00.STEP, 30-YS-0004-00.STEP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]
2023-07-05 Added STEP models
    [1524T_SR.SLDPRT, 16-705-831-540-Z-0000.stp.SLDPRT, 16-708-031-109-Z-0000.stp.SLDPRT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]
2023-07-30 update files
    [1524T_SR.SLDPRT, 16-705-831-540-Z-0000.stp.SLDPRT, 16-708-031-109-Z-0000.stp.SLDPRT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]

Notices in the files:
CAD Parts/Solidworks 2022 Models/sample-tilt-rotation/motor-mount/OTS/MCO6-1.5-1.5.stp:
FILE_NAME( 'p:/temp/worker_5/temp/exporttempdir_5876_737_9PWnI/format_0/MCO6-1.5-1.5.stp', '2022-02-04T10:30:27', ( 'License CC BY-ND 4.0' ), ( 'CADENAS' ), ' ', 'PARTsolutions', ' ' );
